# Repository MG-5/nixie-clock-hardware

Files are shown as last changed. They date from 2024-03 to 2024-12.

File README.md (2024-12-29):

# nixie-clock-hardware
Hardware for controlling six Nixie IN-14 tubes as clock (HH:MM:SS)

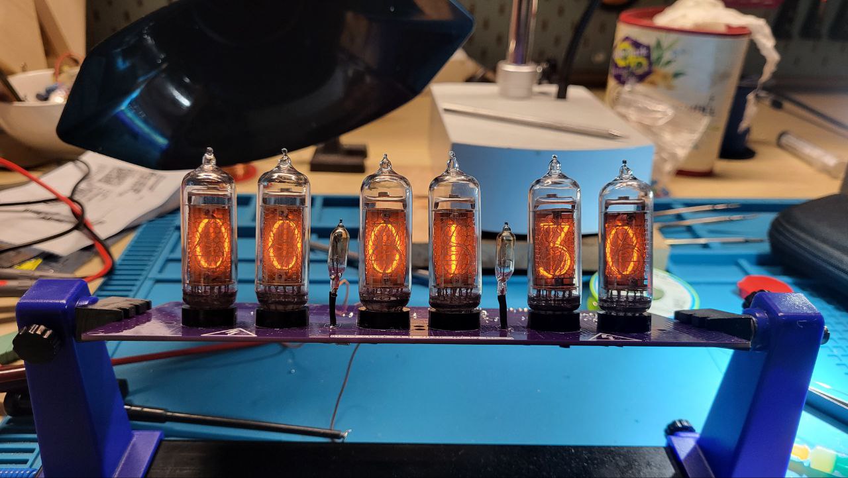
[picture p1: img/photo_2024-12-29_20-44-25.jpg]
finished nixie clock assembled nixie-clock


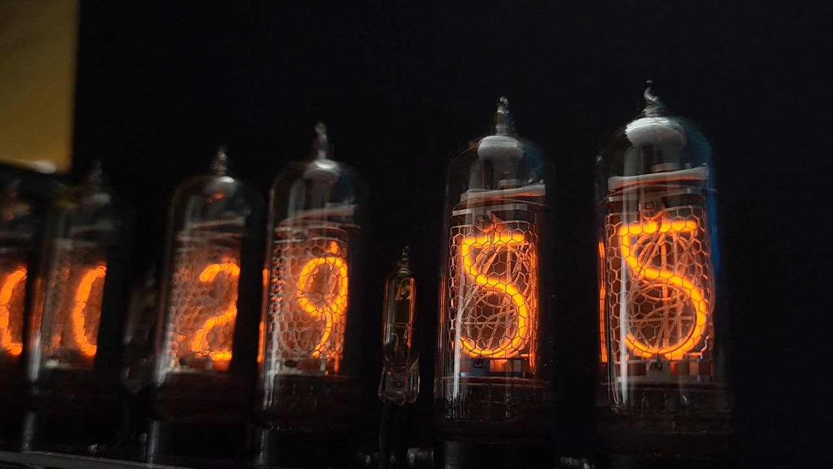
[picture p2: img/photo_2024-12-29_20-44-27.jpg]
finished nixie clock 2 assembled nixie-clock


### Requirements for rev 1.0
* efficient step-boost converter up to 190V
* multiplexing
* control syncronous addressable LEDs
* PWM control
* I²C interface
* connector for ESP (UART)
* time syncronisation line for every second

### Known issues in rev 1.0
* octal buffer for PWM use seems do not works for dimming
  * workaround: dimming solved by adding turn-off points in mulitplexing routine (firmware-based solution)
* bad mosfet selection -> high R_DSOn lead to heat at high current due diode reverse current shots
  * workaround: use better Mosfet with TDSON-8 footprint that can be soldered onto the existing one
  * caution: soldering TDSON-8 with thermal pad on back causes short circuit due to untented via underneath pad
* output cap is to small -> causes high voltage ripple
  * workaround:
    * add 2.2uF with 2220 footprint
    * add 180uF electrolytic cap
* ESD protection on ARGB connector has wrong wiring
  * workaround: do not use USBLC6 and add enameled copper wires

### Renderings (rev 1.0)

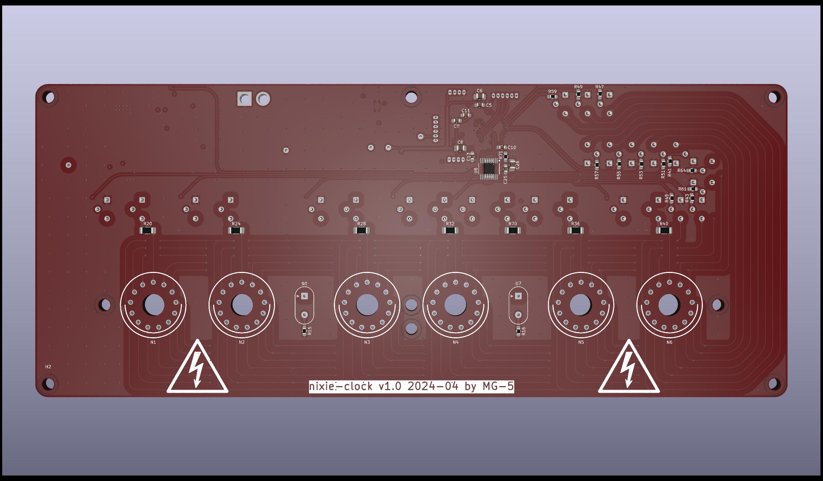
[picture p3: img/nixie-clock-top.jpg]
pcb top nixie-clock PCB v1.0 top view


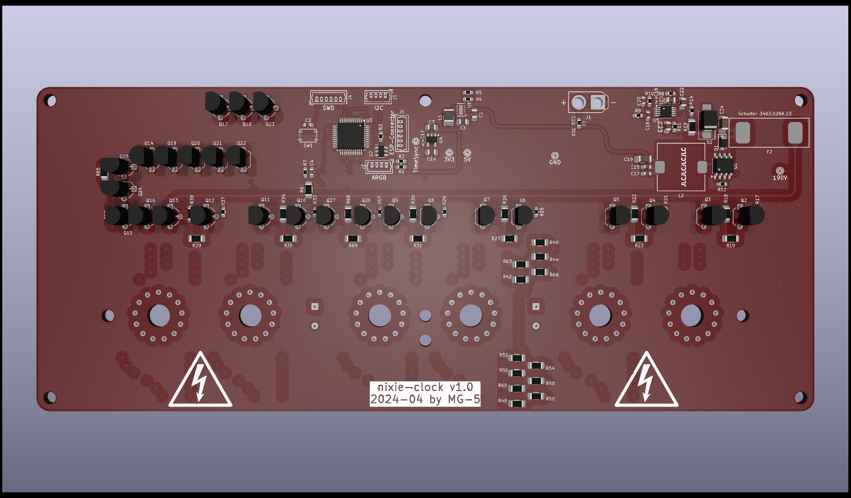
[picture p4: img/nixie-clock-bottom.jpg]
pcb bottom nixie-clock PCB v1.0 bottom view


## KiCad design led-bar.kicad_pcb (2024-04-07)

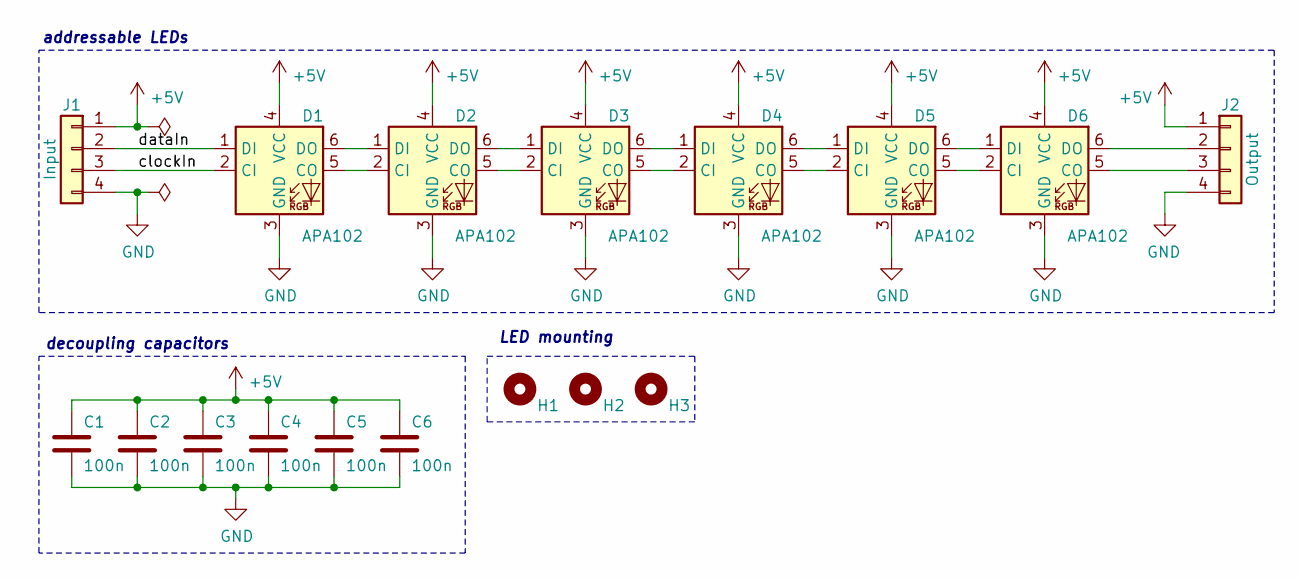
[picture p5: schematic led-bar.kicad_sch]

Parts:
C1, C2, C3, C4, C5, C6: 100n; C_0603_1608Metric_Pad1.08x0.95mm_HandSolder
D1, D2, D3, D4, D5, D6: APA102; LED_RGB_5050-6
H1, H2, H3: MountingHole_Pad; MountingHole_3.2mm_M3_ISO14580
J1: Input; Molex_PicoBlade_53047-0410_1x04_P1.25mm_Vertical
J2: Output; Molex_PicoBlade_53047-0410_1x04_P1.25mm_Vertical

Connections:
+5V: C1.1, C2.1, C3.1, C4.1, C5.1, C6.1, D1.4 (VCC), D2.4 (VCC), D3.4 (VCC), D4.4 (VCC), D5.4 (VCC), D6.4 (VCC), J1.1, J2.1
/clockIn: D1.2 (CI), J1.3
/dataIn: D1.1 (DI), J1.2
GND: C1.2, C2.2, C3.2, C4.2, C5.2, C6.2, D1.3 (GND), D2.3 (GND), D3.3 (GND), D4.3 (GND), D5.3 (GND), D6.3 (GND), J1.4, J2.4
unnamed: D1.5 (CO), D2.2 (CI)
unnamed: D1.6 (DO), D2.1 (DI)
unnamed: D2.5 (CO), D3.2 (CI)
unnamed: D2.6 (DO), D3.1 (DI)
unnamed: D3.5 (CO), D4.2 (CI)
unnamed: D3.6 (DO), D4.1 (DI)
unnamed: D4.5 (CO), D5.2 (CI)
unnamed: D4.6 (DO), D5.1 (DI)
unnamed: D5.5 (CO), D6.2 (CI)
unnamed: D5.6 (DO), D6.1 (DI)
unnamed: D6.5 (CO), J2.3
unnamed: D6.6 (DO), J2.2

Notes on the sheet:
addressable LEDs
decoupling capacitors
LED mounting

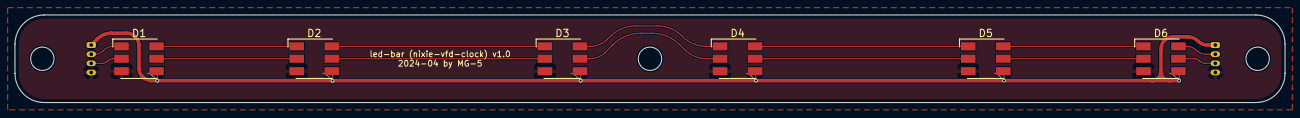
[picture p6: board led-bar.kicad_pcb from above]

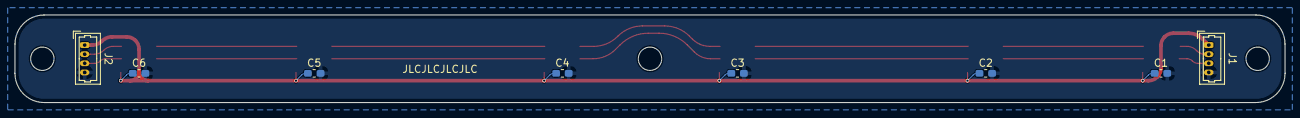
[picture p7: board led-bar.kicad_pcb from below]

Board: 2 copper layers, 174.0 x 12.0 mm, 17 parts (8 on the bottom side), 16 nets.

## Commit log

2024-03-01 Init KiCad project
    [nixie-vfd-clock.kicad_pcb, nixie-vfd-clock.kicad_sch]
2024-03-01 Add submodule with Nixie tube symbols and footprints
2024-03-07 Add Schematic
    [high-side-switch.kicad_sch, low-side-switch.kicad_sch, nixie-clock.kicad_pcb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]
2024-03-17 Add PCB and update Schematic
    [high-side-switch.kicad_sch, led-bar.kicad_pcb, led-bar.kicad_sch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]
2024-03-28 Add dimming option
    [low-side-switch.kicad_sch, nixie-clock.kicad_sch]
2024-04-05 Some finish workings
    [nixie-clock.kicad_sch]
2024-04-07 Further workings on final design
    [led-bar.kicad_pcb]
2024-05-05 Update values to soldered ones
    [high-side-switch.kicad_sch, low-side-switch-dp.kicad_sch, low-side-switch.kicad_sch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]
2024-05-05 Change diode in boost converter circuit
    [nixie-clock.kicad_sch]
2024-06-13 Add know issues to ReadMe, change some values according to simulation
    [nixie-clock.kicad_sch]
2024-08-06 Add note to ESD protection on ARGB connector
    [nixie-clock.kicad_sch]
2024-12-29 Add assembled clock images to ReadMe
